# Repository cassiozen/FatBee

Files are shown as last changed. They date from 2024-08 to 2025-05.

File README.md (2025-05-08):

# Fat Bee 🐝

## A familiar keyboard with unfamiliar comfort

<p align="center" width="100%">
  
</p>

**Fat Bee** is a compact mechanical keyboard that takes a gentle, scientific approach to ergonomics without making you relearn how to type.

## What?

The keyboard layout we use today is ancient. Literally. It was designed in the 1800s to keep typewriters from jamming — not to keep your wrists from hurting.

Modern ergonomic keyboards try to fix that, but many go too far. Curved key wells, columnar layouts, and deep splits can help *if* you’re willing to adapt. Most people aren't.

**Fat Bee bridges the gap between comfort and familiarity.**
It's the kind of keyboard you can sit down at and just start using — whether you hunt and peck, type with two fingers, or mastered touch typing in high school.

## Gallery

<p align="center" width="100%">

</p>

## What's in this repo?

- 3D-print case & palm rest source
- PCB source (KiCad)
- Keyboard layout (standard keyboard-layout-editor.com JSON)
- ZMK profile (coming soon)

## FatBee's Characteristics

### 👐 Gently split layout  

Just enough angle to align your hands naturally.  
**Reduces ulnar deviation** — that awkward wrist bend that causes strain over time.

### 🏕️ 5.5° tenting

Raises the inner edge of the keyboard to match your forearm's natural rotation.  
**Avoids pronation**, keeps your forearm bones from squeezing the carpal tunnel.

### 🛏️ Built-in palm rest + low rear angle

Supports your hands without forcing your wrists to bend upward.  
**Prevents wrist extension**, a common source of fatigue.

### 🧲 Centralized alphas

Alphanumerics are dead center, not off to the left side.  
**Keeps your arms and shoulders aligned** with your body.

## The control cluster you didn’t know you needed

While redesigning the layout, something unexpected happened.

By centering the keys and adjusting row spacing, we created a weird little negative space on the left. Instead of ignoring it, we filled it with function:

- **Escape**, aligned with the numeric row
  (no layer gymnastics for `~` and `'`)
- **Fn key + 3 utility buttons**:
  - Volume up (tap), volume down (Fn+tap)  
  - Brightness up/down  
  - App switcher (like Cmd+Tab / Shift+Cmd+Tab)

## Specs

- 69 keys, number row, arrow cluster
- Low-profile Choc switches

## Inspiration

- **Apple keyboards** – Subtly decreasing row stagger (between rows R2 and R3) since forever. Probably for style. Still, it adds up - used on FatBee.  
- **[Jones layout](https://github.com/jpskenn/Jones)** – Combines centralized alphanumerics with non-staggered rows R2-R3.
- **[Logitech Wave](https://www.logitech.com/en-us/products/keyboards/wave-keys.html)** - Despite feeling mushy and cheap, it does deliver great ergonomic improvements while still looking familiar.

## License

CERN Open Hardware Licence Version 2 - Weakly Reciprocal (CERN-OHL-W V2).

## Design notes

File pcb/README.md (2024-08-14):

The PCB is supposed to be bended to accomodate for the 3 different tenting angles. It has a cutting pattern on the middle to facilitate this, and should be manufactured with 0.6mm thickness.

# PCB characteristics:

- Kailh sockets for hot swaping
- Header pins to connect a Nice!nano or compatible microcontroller board.
- 

# Grid

To optimize the number of required pins, the PCB is wired in a virtual row/column matrix with 7 columns and 10 rows. The columns are wired in pairs, meaning each virtual column spans across two physical key columns. The left side of the PCB is exclusively wired to the odd-numbered rows, while the right side is wired exclusively to the even-numbered rows.

## Warning

Still under development, use at your own risk. I just ordered this version from JLCPCB and if it works I'll be glad to remove this warning ;)

## What's up with all those screws?

There are three constraints:

- Make it bend
- Make it sturdy enough for hotswap to work
- Make it practical, using common materials and manufacturing practices (so one can use services like PCBWay or JLCPCB...)

venn

> "I don't know... Have you tried a thin PCB with, like, lots of screws?".
>> Brain cell on the back, hand raised, a little bit ashamed of the suggestion.

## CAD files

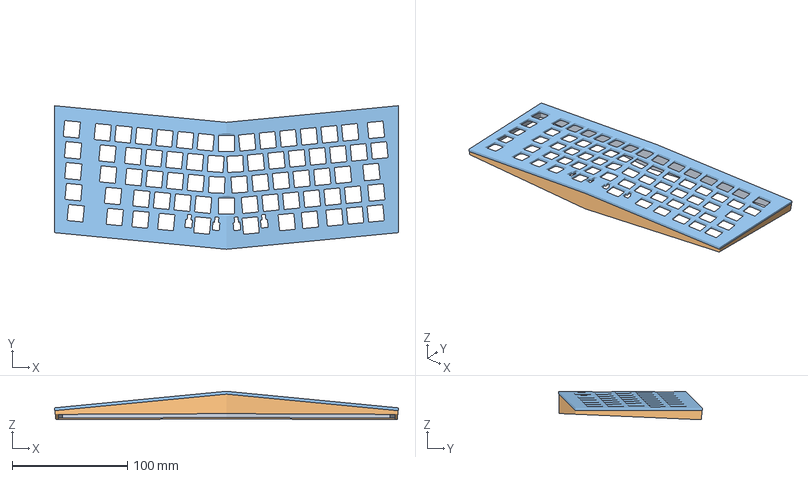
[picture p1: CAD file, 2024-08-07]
3d_print/FatBee.3mf
298.6 x 124.6 x 24.7 mm
inner_walls
outer_walls
plate

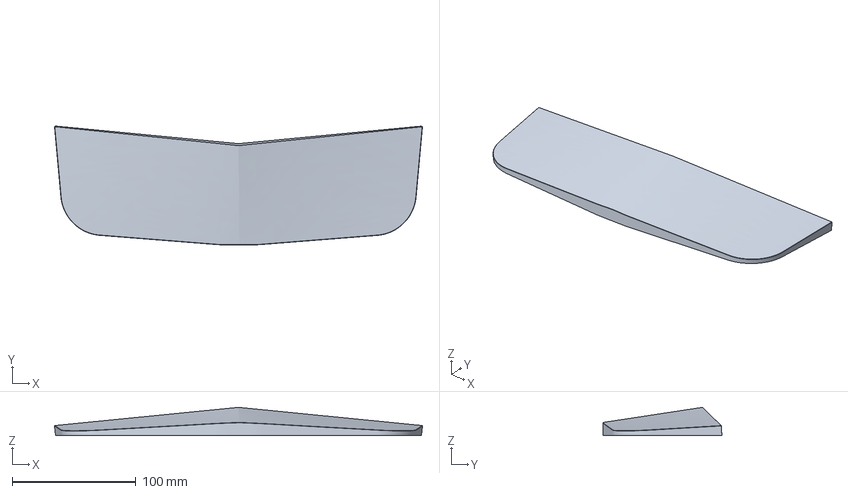
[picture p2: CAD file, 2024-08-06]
3d_print/palmrest.3mf
297.9 x 96.2 x 22.9 mm

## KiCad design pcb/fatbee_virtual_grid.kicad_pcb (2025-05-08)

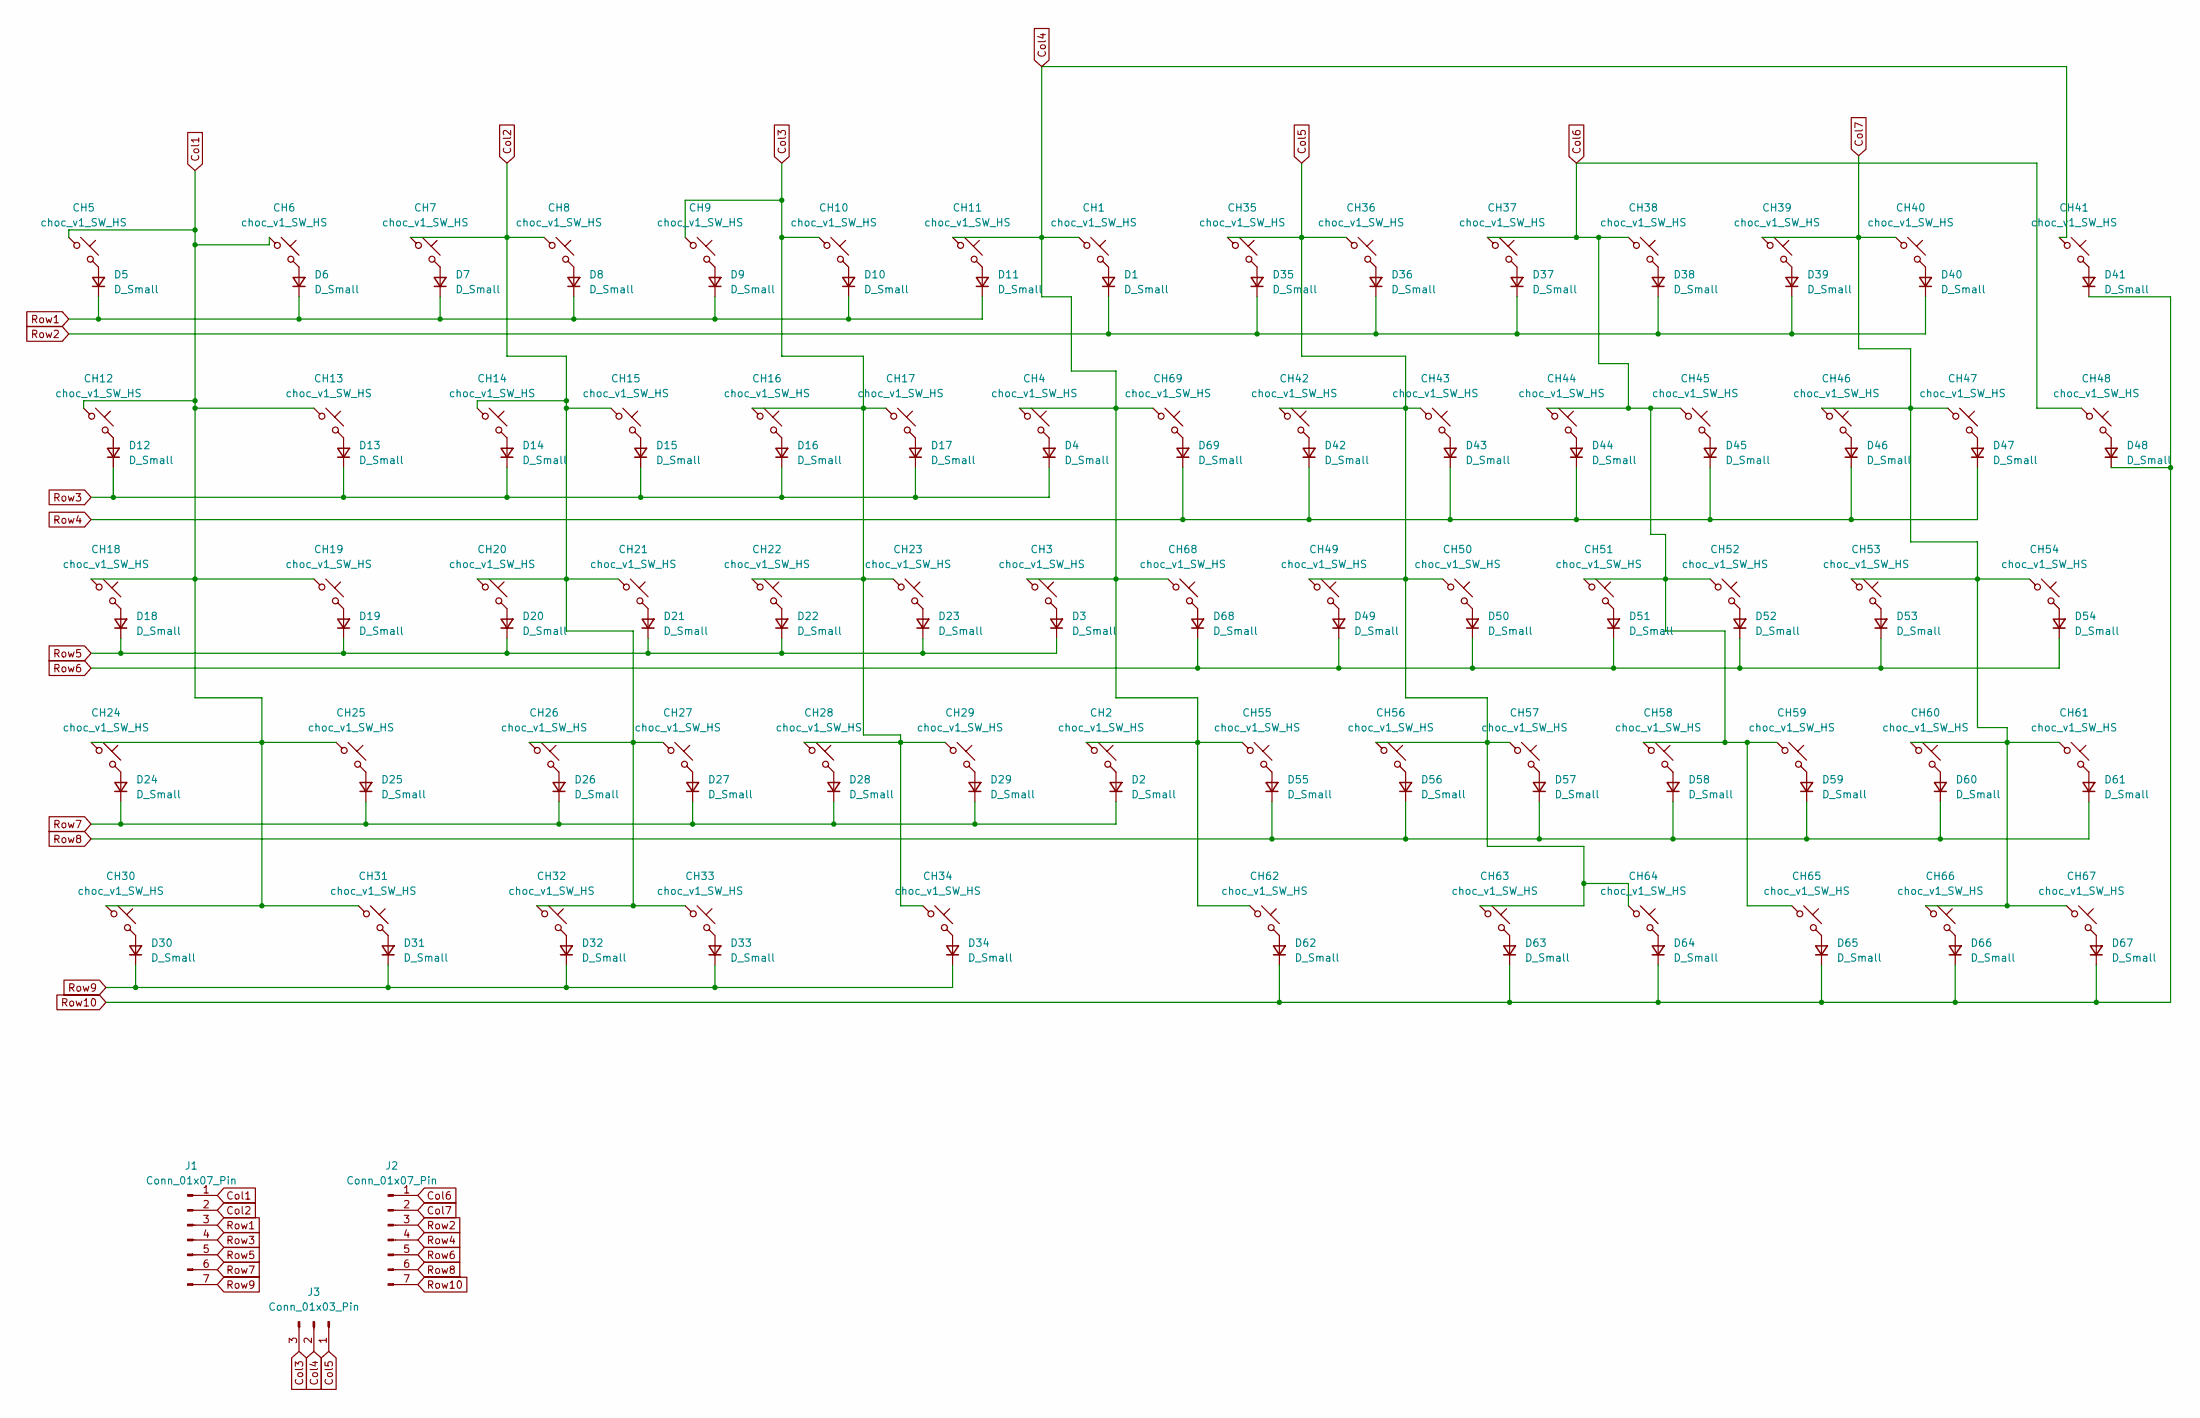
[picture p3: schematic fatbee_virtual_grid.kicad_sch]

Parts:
CH1, CH2, CH3, CH4, CH5, CH6, CH7, CH8, CH9, CH10, CH11, CH12, CH13, CH14, CH15, CH16, CH17, CH18, CH19, CH20, CH21, CH22, CH23, CH24, CH25, CH26, CH27, CH28, CH29, CH30, CH31, CH32, CH33, CH34, CH35, CH36, CH37, CH38, CH39, CH40, CH41, CH42, CH43, CH44, CH45, CH46, CH47, CH48, CH49, CH50, CH51, CH52, CH53, CH54, CH55, CH56, CH57, CH58, CH59, CH60, CH61, CH62, CH63, CH64, CH65, CH66, CH67, CH68, CH69: choc_v1_SW_HS; SW_choc_v1_HS_CPG135001S30_1u
D1, D2, D3, D4, D5, D6, D7, D8, D9, D10, D11, D12, D13, D14, D15, D16, D17, D18, D19, D20, D21, D22, D23, D24, D25, D26, D27, D28, D29, D30, D31, D32, D33, D34, D35, D36, D37, D38, D39, D40, D41, D42, D43, D44, D45, D46, D47, D48, D49, D50, D51, D52, D53, D54, D55, D56, D57, D58, D59, D60, D61, D62, D63, D64, D65, D66, D67, D68, D69: D_Small; D_SOD-123
J1, J2: Conn_01x07_Pin; PinHeader_1x07_P2.54mm_Vertical
J3: Conn_01x03_Pin; PinHeader_1x03_P2.54mm_Vertical

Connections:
Col1: CH5.1, CH6.1, CH12.1, CH13.1, CH18.1, CH19.1, CH24.1, CH25.1, CH30.1, CH31.1, J1.1
Col2: CH7.1, CH8.1, CH14.1, CH15.1, CH20.1, CH21.1, CH26.1, CH27.1, CH32.1, CH33.1, J1.2
Col3: CH9.1, CH10.1, CH16.1, CH17.1, CH22.1, CH23.1, CH28.1, CH29.1, CH34.1, J3.3
Col4: CH1.1, CH2.1, CH3.1, CH4.1, CH11.1, CH41.1, CH55.1, CH62.1, CH68.1, CH69.1, J3.2
Col5: CH35.1, CH36.1, CH42.1, CH43.1, CH49.1, CH50.1, CH56.1, CH57.1, CH63.1, CH64.1, J3.1
Col6: CH37.1, CH38.1, CH44.1, CH45.1, CH48.1, CH51.1, CH52.1, CH58.1, CH59.1, CH65.1, J2.1
Col7: CH39.1, CH40.1, CH46.1, CH47.1, CH53.1, CH54.1, CH60.1, CH61.1, CH66.1, CH67.1, J2.2
unnamed: CH1.2, D1.2 (A)
unnamed: CH2.2, D2.2 (A)
unnamed: CH3.2, D3.2 (A)
unnamed: CH4.2, D4.2 (A)
unnamed: CH5.2, D5.2 (A)
unnamed: CH6.2, D6.2 (A)
unnamed: CH7.2, D7.2 (A)
unnamed: CH8.2, D8.2 (A)
unnamed: CH9.2, D9.2 (A)
unnamed: CH10.2, D10.2 (A)
unnamed: CH11.2, D11.2 (A)
unnamed: CH12.2, D12.2 (A)
unnamed: CH13.2, D13.2 (A)
unnamed: CH14.2, D14.2 (A)
unnamed: CH15.2, D15.2 (A)
unnamed: CH16.2, D16.2 (A)
unnamed: CH17.2, D17.2 (A)
unnamed: CH18.2, D18.2 (A)
unnamed: CH19.2, D19.2 (A)
unnamed: CH20.2, D20.2 (A)
unnamed: CH21.2, D21.2 (A)
unnamed: CH22.2, D22.2 (A)
unnamed: CH23.2, D23.2 (A)
unnamed: CH24.2, D24.2 (A)
unnamed: CH25.2, D25.2 (A)
unnamed: CH26.2, D26.2 (A)
unnamed: CH27.2, D27.2 (A)
unnamed: CH28.2, D28.2 (A)
unnamed: CH29.2, D29.2 (A)
unnamed: CH30.2, D30.2 (A)
unnamed: CH31.2, D31.2 (A)
unnamed: CH32.2, D32.2 (A)
unnamed: CH33.2, D33.2 (A)
unnamed: CH34.2, D34.2 (A)
unnamed: CH35.2, D35.2 (A)
unnamed: CH36.2, D36.2 (A)
unnamed: CH37.2, D37.2 (A)
unnamed: CH38.2, D38.2 (A)
unnamed: CH39.2, D39.2 (A)
unnamed: CH40.2, D40.2 (A)
unnamed: CH41.2, D41.2 (A)
unnamed: CH42.2, D42.2 (A)
unnamed: CH43.2, D43.2 (A)
unnamed: CH44.2, D44.2 (A)
unnamed: CH45.2, D45.2 (A)
unnamed: CH46.2, D46.2 (A)
unnamed: CH47.2, D47.2 (A)
unnamed: CH48.2, D48.2 (A)
unnamed: CH49.2, D49.2 (A)
unnamed: CH50.2, D50.2 (A)
unnamed: CH51.2, D51.2 (A)
unnamed: CH52.2, D52.2 (A)
unnamed: CH53.2, D53.2 (A)
unnamed: CH54.2, D54.2 (A)
unnamed: CH55.2, D55.2 (A)
unnamed: CH56.2, D56.2 (A)
unnamed: CH57.2, D57.2 (A)
unnamed: CH58.2, D58.2 (A)
unnamed: CH59.2, D59.2 (A)
unnamed: CH60.2, D60.2 (A)
unnamed: CH61.2, D61.2 (A)
unnamed: CH62.2, D62.2 (A)
unnamed: CH63.2, D63.2 (A)
unnamed: CH64.2, D64.2 (A)
unnamed: CH65.2, D65.2 (A)
unnamed: CH66.2, D66.2 (A)
unnamed: CH67.2, D67.2 (A)
unnamed: CH68.2, D68.2 (A)
unnamed: CH69.2, D69.2 (A)
Row1: D5.1 (K), D6.1 (K), D7.1 (K), D8.1 (K), D9.1 (K), D10.1 (K), D11.1 (K), J1.3
Row2: D1.1 (K), D35.1 (K), D36.1 (K), D37.1 (K), D38.1 (K), D39.1 (K), D40.1 (K), J2.3
Row3: D4.1 (K), D12.1 (K), D13.1 (K), D14.1 (K), D15.1 (K), D16.1 (K), D17.1 (K), J1.4
Row4: D42.1 (K), D43.1 (K), D44.1 (K), D45.1 (K), D46.1 (K), D47.1 (K), D69.1 (K), J2.4
Row5: D3.1 (K), D18.1 (K), D19.1 (K), D20.1 (K), D21.1 (K), D22.1 (K), D23.1 (K), J1.5
Row6: D49.1 (K), D50.1 (K), D51.1 (K), D52.1 (K), D53.1 (K), D54.1 (K), D68.1 (K), J2.5
Row7: D2.1 (K), D24.1 (K), D25.1 (K), D26.1 (K), D27.1 (K), D28.1 (K), D29.1 (K), J1.6
Row8: D55.1 (K), D56.1 (K), D57.1 (K), D58.1 (K), D59.1 (K), D60.1 (K), D61.1 (K), J2.6
Row9: D30.1 (K), D31.1 (K), D32.1 (K), D33.1 (K), D34.1 (K), J1.7
Row10: D41.1 (K), D48.1 (K), D62.1 (K), D63.1 (K), D64.1 (K), D65.1 (K), D66.1 (K), D67.1 (K), J2.7

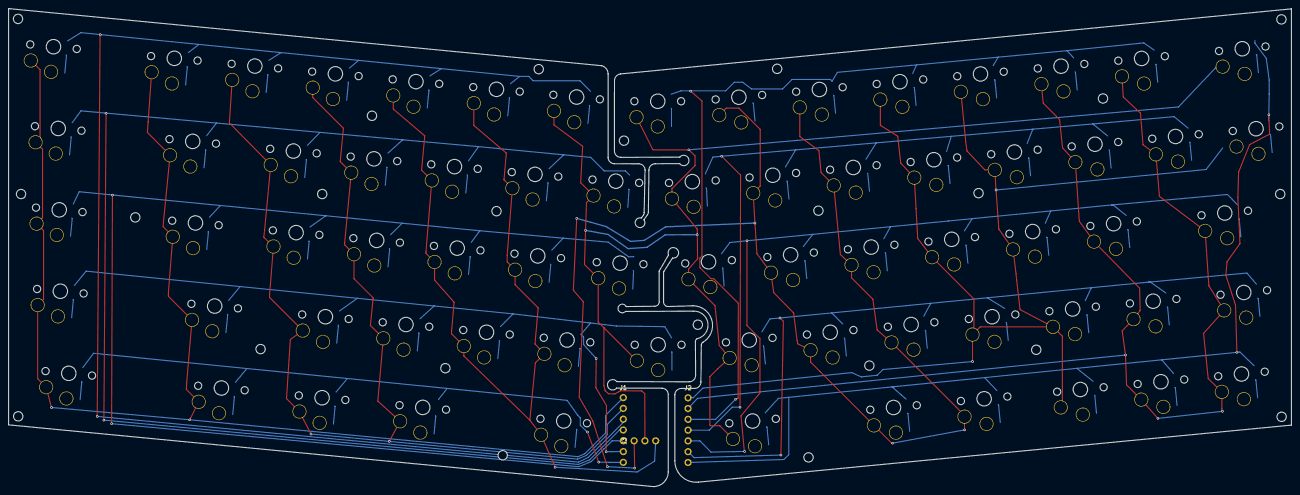
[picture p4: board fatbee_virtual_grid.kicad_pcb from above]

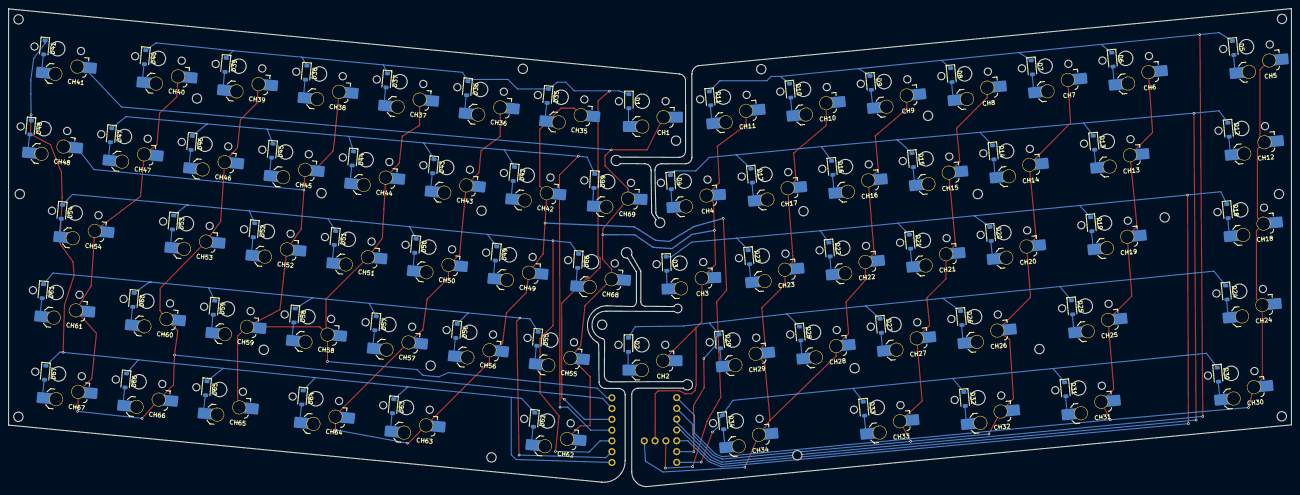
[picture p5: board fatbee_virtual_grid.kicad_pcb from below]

Board: 2 copper layers, 302.0 x 112.5 mm, 141 parts (138 on the bottom side), 86 nets.

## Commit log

2024-08-07 Slightly size adjustments on central keys
    [FatBee.3mf]
2024-08-07 left half PCB beta
    [left.kicad_pcb, left.kicad_sch]
2024-08-07 PCB Readme
2024-08-14 PCB maybe working?
    [fatbee_virtual_grid.kicad_pcb, fatbee_virtual_grid.kicad_sch, left.kicad_pcb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]
2024-08-14 Updated PCB readme
2025-05-08 four thousand holes in Blackburn Lancashire
    [fatbee_virtual_grid.kicad_pcb]
